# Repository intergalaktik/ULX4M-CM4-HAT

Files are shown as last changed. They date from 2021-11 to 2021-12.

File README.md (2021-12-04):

# ULX4M-CM4-HAT

###

On V1 we have FTDI to FPGA working and we can upload bitstream to FPGA, serial passtrue is also working.
For some reason it was hard to put ESP32 into bootloader mode, and I was not able to load micropython while shiled was connected to FPGA.
After doing that directly (bricking pins on shield FTDI TX > ESP32 RX, ESP32 TX > FTDI RX, GPIO0 > GND) I have succesfully loaded micropython on ESP32.
WROOM is still not perfect fit as it has low memory.
WROWER can access shared SD card, and flash FPGA over WIFI.

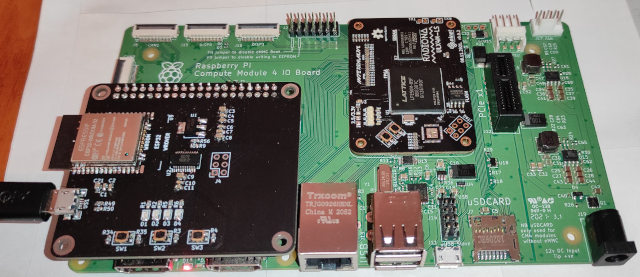
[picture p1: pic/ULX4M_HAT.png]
ULX4M_HAT


### Current pinout

cm4_gpio|wifi_gpio|HAT function|FPGA|FPGA
--- | --- | --- | --- | --
0 | 21 | SDA0 | P17 |
1 | 22 | SCL0 | P16 |
2 | 12 | SD_D2 | K1 | K5
3 | 4 | SD_D1 | H1 | J5
4 | 2 | SD_D0 | J3 | K4
5 | 33 | | H16 |
6 |  | BTN1 | R1 |
7 |  | BTN2 | P3 |
8 | 19 | | P4 |
9 | 27 | | G16 |
10 | 26 | | N17 |
11 | 25 | | L16 |
12 | 23 | TDI | R5 |
13 |  | FTDI_TXDEN | T1 |
14 | 13 | SD_D3 | K2 | L4
15 | 14 | SD_CLK | H2 | L5
16 | 34 | TDO | V4 | 
17 | 35 | | N17 |
18 | | LED1 | N5 |
19 | 0 | BOOT_PULL_UP | U1
20 | 18 | TCK | T5 |
21 | 5 | TMS | U5 |
22 | EN | WIFI_EN | U18
23 |  | FTDI_TXD | N4 |
24 |  | FTDI_RX | N3 |
25 | RXD0 | WIFI_RDX | P5 |
26 | TXD0 | WIFI_TXD | V1 |
27 | 15 | SD_CMD | J1 | N16

### ToDo

- [x] FTDI chip
- [x] USB
- [x] FTDI JTAG connected to FPGA
- [x] FTDI UART connected to FPGA
- [x] ESP32 UART connected to FPGA
- [x] ESP32 connected to SD card that is connected to FPGA ( SD card sharing )
- [x] LEDS
- [x] BTNS
- [ ] USBC
- [ ] 8 LEDs
- [ ] 8 BTNs
- [ ] ESP32 WROM
- [ ] ESP32 WROVER
- [ ] ESP32 S2 
- [ ] ESP32 S3
- [ ] FT4232
- [ ] USB A host connector connected directly to FPGA
- [ ] I2S Audio
- [ ] Audio amplifier
- [ ] PMOD connector/connectors

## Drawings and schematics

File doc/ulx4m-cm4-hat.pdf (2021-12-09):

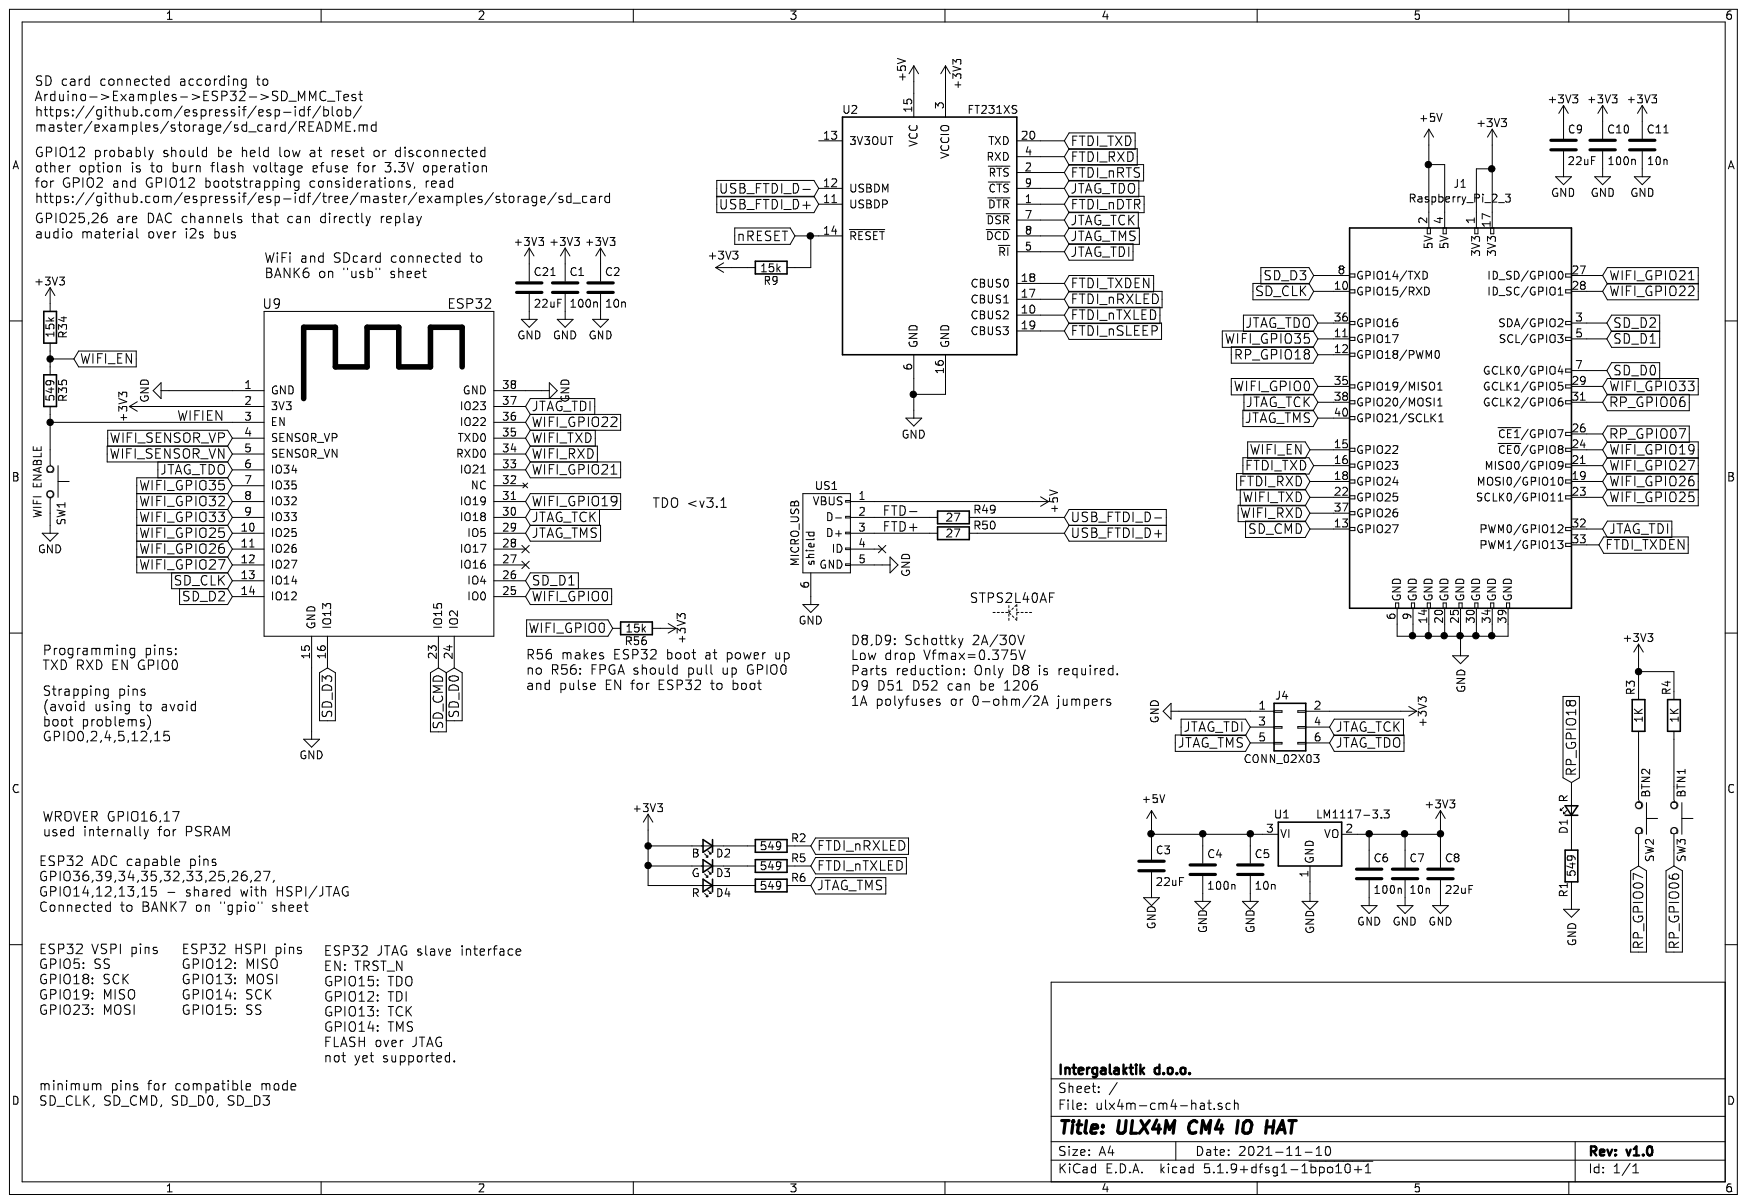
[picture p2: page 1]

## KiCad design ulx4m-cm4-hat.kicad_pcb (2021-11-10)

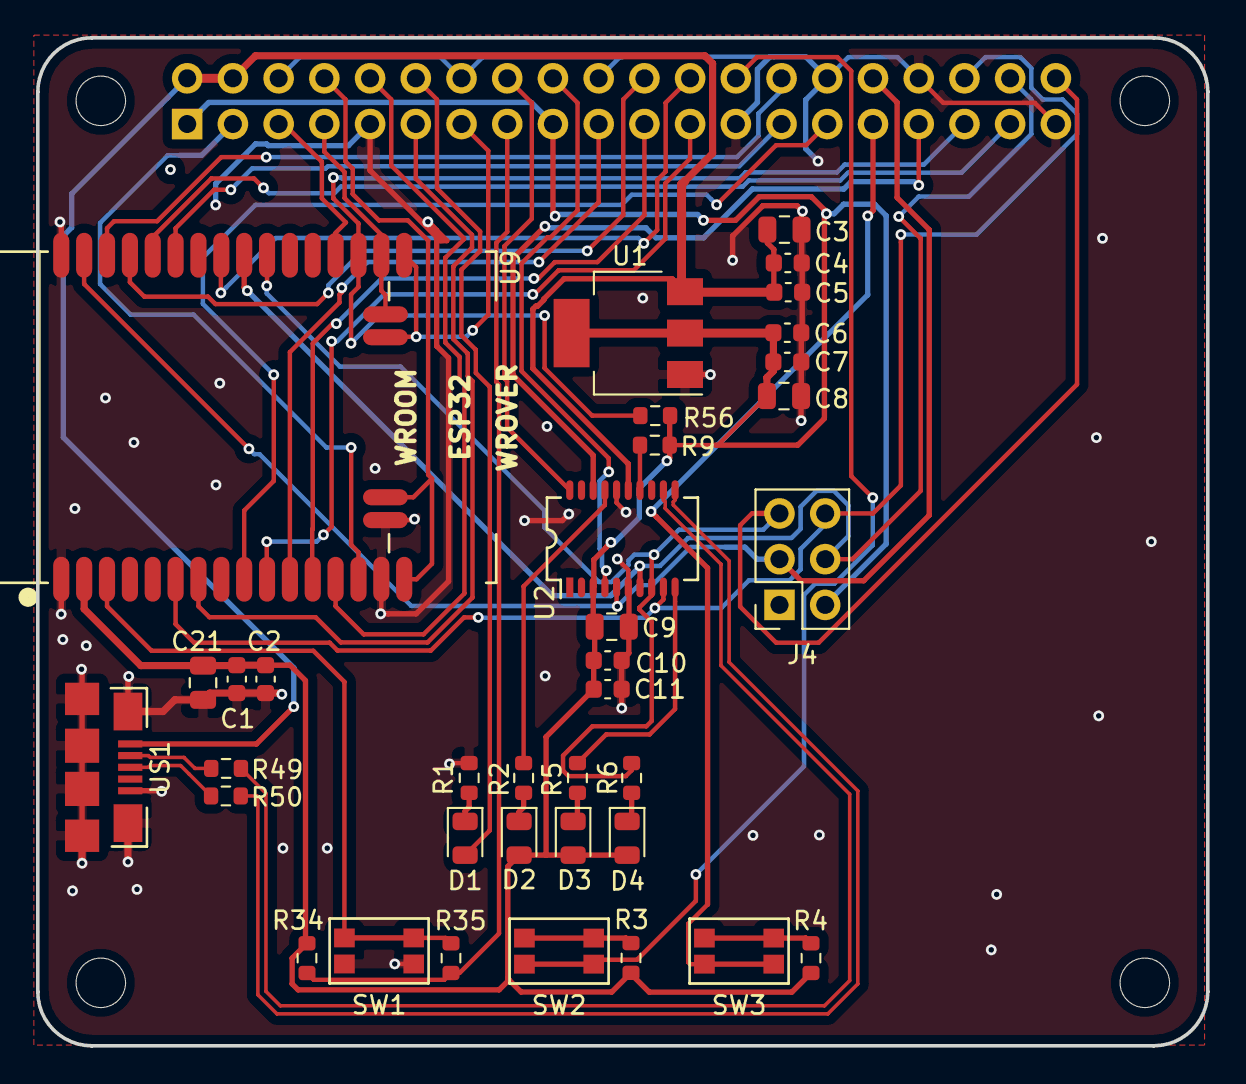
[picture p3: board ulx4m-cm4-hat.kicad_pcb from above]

Board: 4 copper layers, 65.0 x 56.0 mm, 41 parts (1 on the bottom side), 45 nets.

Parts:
C1, C4, C6, C10: 100n; C_0603_1608Metric
C2, C5, C7, C11: 10n; C_0603_1608Metric
C3, C8, C9, C21: 22uF; C_0805_2012Metric
D1, D4: R; LED_0805_2012Metric
D2: B; LED_0805_2012Metric
D3: G; LED_0805_2012Metric
H1, H2, H5, H6: MountingHole; MountingHole_2.75mm_NoPad
J1: Raspberry_Pi_2_3; PinSocket_2x20_P2.54mm_Vertical
J4: CONN_02X03; PinSocket_2x03_P2.54mm_Vertical
R1, R2, R5, R6, R35: 549; R_0603_1608Metric
R3, R4: 1K; R_0603_1608Metric
R9, R34, R56: 15k; R_0603_1608Metric
R49, R50: 27; R_0603_1608Metric
SW1: WIFI ENABLE; Switch_EVPAA
SW2: BTN2; Switch_EVPAA
SW3: BTN1; Switch_EVPAA
U1: LM1117-3.3; SOT-223-3_TabPin2
U2: FT231XS; FT231X-SSOP-20_4.4x6.5mm_Pitch0.65mm
U9: ESP32
US1: MICRO_USB; USB-MICRO-B-FCI-10118192-0001LF

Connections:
+3V3: C1.1, C2.1, C6.1, C7.1, C8.1, C9.1, C10.1, C11.1, C21.1, D2.2, D3.2, D4.2, J1.1, J1.17, J4.2, R3.1, R4.1, R9.2, R34.1, R56.1, U1.2, U2.3, U9.2
+5V: C3.1, C4.1, C5.1, J1.2, J1.4, U1.3, U2.15, US1.1
/FTD+: R50.2, US1.3
/FTD-: R49.2, US1.2
/WIFIEN: R35.2, SW1.1, U9.3
FTDI_RXD: J1.18, U2.4
FTDI_TXD: J1.16, U2.20
FTDI_TXDEN: J1.33, U2.18
FTDI_nRXLED: R2.1, U2.17
FTDI_nTXLED: R5.1, U2.10
GND: C1.2, C2.2, C3.2, C4.2, C5.2, C6.2, C7.2, C8.2, C9.2, C10.2, C11.2, C21.2, J1.6, J1.9, J1.14, J1.20, J1.25, J1.30, J1.34, J1.39, J4.1, R1.2, SW1.2, U1.1, U2.6, U2.16, U9.1, U9.15, U9.38, US1.5, US1.6
JTAG_TCK: J1.38, J4.4, U2.7, U9.30
JTAG_TDI: J1.32, J4.3, U2.5, U9.37
JTAG_TDO: J1.36, J4.6, U2.9, U9.6
JTAG_TMS: J1.40, J4.5, R6.1, U2.8, U9.29
unnamed: D1.1, R1.1
unnamed: D2.1, R2.2
unnamed: D3.1, R5.2
unnamed: D4.1, R6.2
unnamed: R3.2, SW2.1
unnamed: R4.2, SW3.1
RP_GPIO06: J1.31, SW3.2
RP_GPIO07: J1.26, SW2.2
RP_GPIO18: D1.2, J1.12
SD_CLK: J1.10, U9.13
SD_CMD: J1.13, U9.23
SD_D0: J1.7, U9.24
SD_D1: J1.5, U9.26
SD_D2: J1.3, U9.14
SD_D3: J1.8, U9.16
USB_FTDI_D+: R50.1, U2.11
USB_FTDI_D-: R49.1, U2.12
WIFI_EN: J1.15, R34.2, R35.1
WIFI_GPIO0: J1.35, R56.2, U9.25
WIFI_GPIO19: J1.24, U9.31
WIFI_GPIO21: J1.27, U9.33
WIFI_GPIO22: J1.28, U9.36
WIFI_GPIO25: J1.23, U9.10
WIFI_GPIO26: J1.19, U9.11
WIFI_GPIO27: J1.21, U9.12
WIFI_GPIO33: J1.29, U9.9
WIFI_GPIO35: J1.11, U9.7
WIFI_RXD: J1.37, U9.34
WIFI_TXD: J1.22, U9.35
nRESET: R9.1, U2.14

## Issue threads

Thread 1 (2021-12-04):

PMOD HAT for ULX4M?

fm4dd, 2021-12-04:
I am looking forward to the kickstarter. Similar to ULX4M-CM4-HAT, I want to test the ULX4M / CM4 IO board combination with the RPI PMOD Hat at  [https://github.com/fm4dd/pmod2rpi](https://github.com/fm4dd/pmod2rpi). I am owning the ULX3S from the previous kickstarter, and although the PMOD interfacing works there, the ULX4M concept is great to interface with standard RPI compute module breakouts.

goran-mahovlic, 2021-12-04:
Thank you! Oooo your HAT looks great. This one here is just first revision that has just small number of functions.
My currrent problem with ULX4M is components sourcing. I currently have parts for only 10 boards, and I have much more people on list that I need to send board. Main things on ULX4M that still need work are SerDes and CSI DSI as that is still left untested. SerDes is only confirmed with Litex with just simple loopback. Plan for this HAT is to have some chip as multiplexer, and also some protection. And it should provide more LEDS, BUTTONS, simple USB host, FTDI, Serial, WIFI, SD card sharing with FPGA.

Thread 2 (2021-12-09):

nDTR, nRTS not connected to ESP32

emard, 2021-12-09:
from nRTS nDTR over 2 NPN transistors to ESP32 EN and IO0 (and IO2 and/or whatever)
for esptool.py work directly, see other esp32 devkit schematics
https://www.reddit.com/r/PrintedCircuitBoard/comments/i7bmt2/esp32_schematic_review/

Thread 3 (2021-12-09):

FT4232 to HAT

emard, 2021-12-09:
Instead of FT231X, Use 4-port FT4232 for HAT
port A: FPGA JTAG (MPSSE capable, programming FPGA)
port B: FPGA GPIO (MPPSE capable, programming user core like linux)
port C: FPGA GPIO (user core serial port general purpose)
port D: ESP32 programming (RX/TX and 2 NPN transistors for programming)

jumpers or switches to swap port B and D (in case of mounting
FT2232 instead of FT4232 to keep all functionality but with manual switching)

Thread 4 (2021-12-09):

SD card not working with ESP32-WROOM

emard, 2021-12-09:
with passthru from DFU,
setting io12 on (this pin is used with SD card) reboots ESP32

>>> from machine import Pin
>>> p12=Pin(12,Pin.OUT)
>>> p12.on()
>>> Started webrepl in normal mode
ssid: ra chan: 1 rssi: -28 authmode: WPA2-PSK
FTP server started on 192.168.48.193:21
NTP not available
MicroPython v1.14 on 2021-02-02; ESP32 module with ESP32
Type "help()" for more information.

emard, 2021-12-09:
second reason why SD card doesn't work is
that wifi pins 2 and 12 are connected together

```
assign led = {wifi_gpio15, wifi_gpio14, wifi_gpio13, wifi_gpio12};

>>> from machine import Pin
>>> p2=Pin(2,Pin.OUT)
>>> p2.on()
>>> p2.off()
>>> p12=Pin(12,Pin.OUT)
>>> p12.on() # same LED turns on as with p2.on()
>>> p12.off()
```

goran-mahovlic, 2021-12-09:
SD card is working on WROVER - so maybe you can check if gpio 2 and gpio 12 are bricked on your HAT board?

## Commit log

2021-11-08 Adding initial files
    [ulx4m-cm4-hat.kicad_pcb, ulx4m-cm4-hat.sch, wifi.sch]
2021-11-10 Version v1.0
    [ulx4m-cm4-hat-B_Cu.gbr, ulx4m-cm4-hat-B_Mask.gbr, ulx4m-cm4-hat-B_Paste.gbr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]
2021-12-09 Adding schematics
